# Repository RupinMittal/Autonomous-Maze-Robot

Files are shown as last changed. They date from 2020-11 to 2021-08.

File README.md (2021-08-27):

# Autonomous Maze Robot

The top right corner is the end of the maze. See the Demo folder for full videos, and below for an overview
of the project. 

maze1
maze2


## Made with IEEE UCLA

### Description

This project is an autononmous maze navigating robot. It was built from scratch with 
the help of IEEE at UCLA (and my leads Bradley Schulz and Tyler Price).

To see the code, go to Code-SRC.
To run the code on your micromous, download the MicroMouse-STM32IDE.zip file, and open in the STM32 Cube IDE, 
so that you have the STM-configured files ready to go. Your robot will need to match the same port connections
in the schematics.

The test for the robots was a modified verison of the AAMC competition at UCLA where the top right corner is
considered the end of the maze.

### Software

The microcontroller used was the STM 32 Microcontoller, so the embedded programs were written in 
the C programming language. 

Includes:
- Motor Control (PID)
- IR Sensor based control
- Floodfill Algorithm
- Simulator (the base of the simulator was written by Tyler Price at IEEE)

The files included in this repository are only the code I wrote, and not the files automatically 
configured by the STM 32 Cube IDE. 

### Hardware 

The base PCB was built by Bradley Schulz and Tyler Price from IEEE UCLA. I have made 
my own schematic designs for the whole project (included in this repository). All schematics were 
made with EAGLE. I designed the IR sensor PCB from scratch using EAGLE software as well.

- Power Board Schematic
- H-Bridge Schematic
- IR Sensor PCB Board

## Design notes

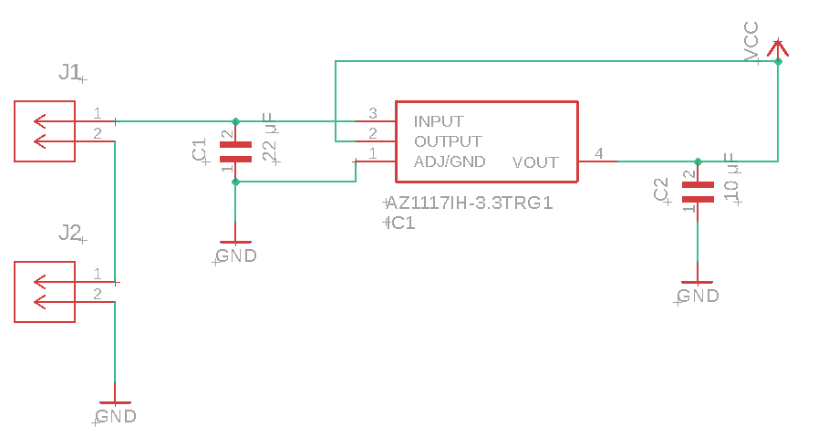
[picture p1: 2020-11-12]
Schematics-PCBs/Power Regulator Schematic.png

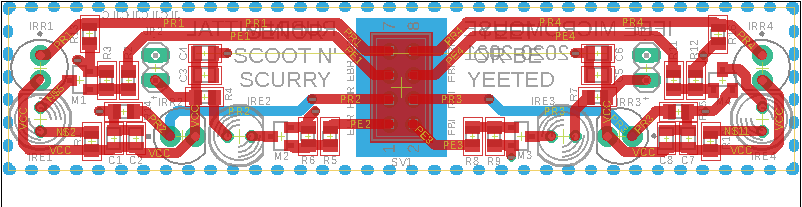
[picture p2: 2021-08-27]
Schematics-PCBs/IR PCB Image.png

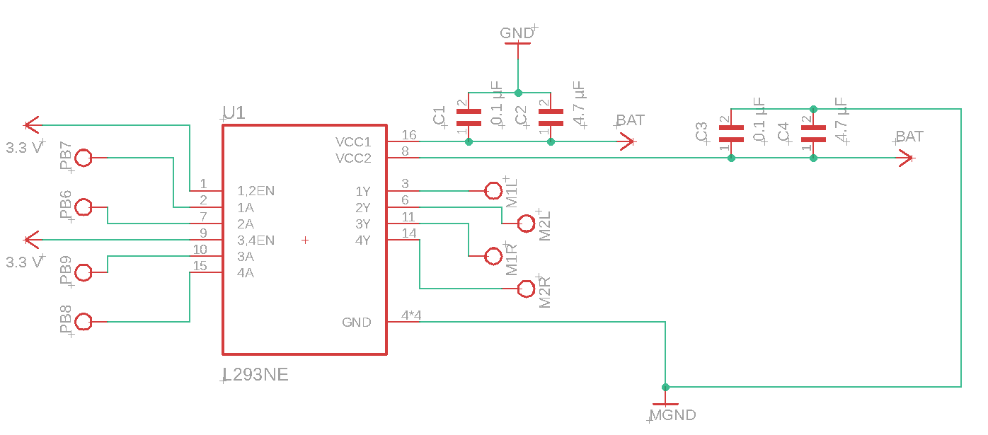
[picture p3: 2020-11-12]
Schematics-PCBs/H-Bridge Schematic.png

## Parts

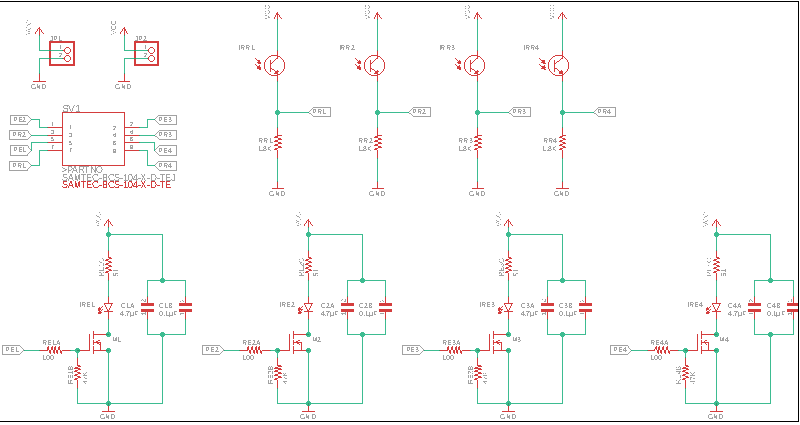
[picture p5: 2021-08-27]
Schematics-PCBs/IR PCB Components.png

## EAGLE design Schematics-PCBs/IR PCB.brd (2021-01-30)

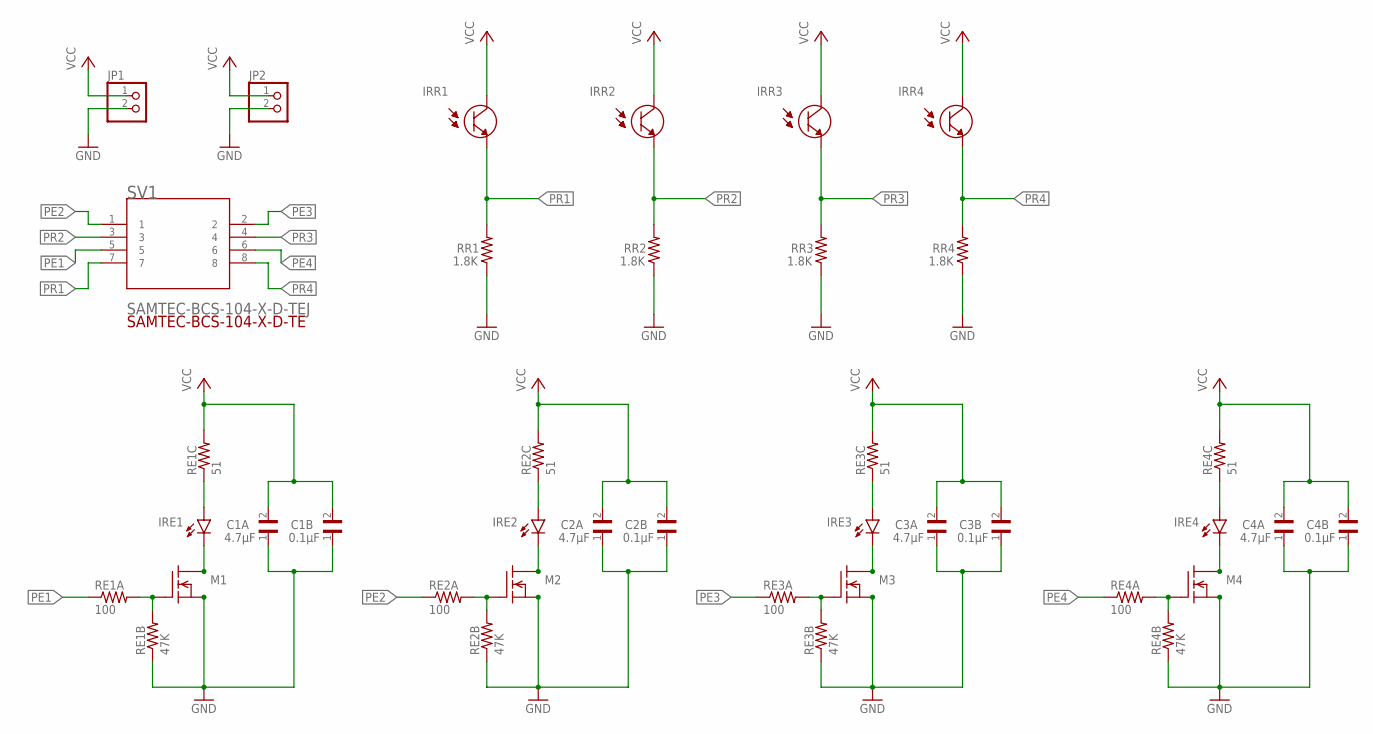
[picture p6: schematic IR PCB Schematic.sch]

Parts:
C1A, C2A, C3A, C4A: 4.7μF; CAPC2012X140N
C1B, C2B, C3B, C4B: 0.1μF; CAPC2012X140N
IRE1, IRE2, IRE3, IRE4: LED5MM
IRR1, IRR2, IRR3, IRR4: SFH_313_FA-3/4; XDCR_SFH_313_FA-3/4
JP1, JP2: PINHD-1X2; 1X02
M1, M2, M3, M4: 2N7002; SOT23
RE1A, RE2A, RE3A, RE4A: 100; R0805
RE1B, RE2B, RE3B, RE4B: 47K; R0805
RE1C, RE2C, RE3C, RE4C: 51; R0805
RR1, RR2, RR3, RR4: 1.8K; R0805
SV1: SAMTEC-BCS-104-X-D-TEJ; SAMTEC-BCS-104-X-D-TE

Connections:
GND: C1A.1, C1B.1, C2A.1, C2B.1, C3A.1, C3B.1, C4A.1, C4B.1, JP1.2, JP2.2, M1.2 (S), M2.2 (S), M3.2 (S), M4.2 (S), RE1B.1, RE2B.1, RE3B.1, RE4B.1, RR1.1, RR2.1, RR3.1, RR4.1
unnamed: M1.1 (G), RE1A.2, RE1B.2
unnamed: IRE1.A, RE1C.1
unnamed: M2.1 (G), RE2A.2, RE2B.2
unnamed: IRE2.A, RE2C.1
unnamed: IRE1.K (C), M1.3 (D)
unnamed: IRE2.K (C), M2.3 (D)
unnamed: M3.1 (G), RE3A.2, RE3B.2
unnamed: IRE3.A, RE3C.1
unnamed: IRE3.K (C), M3.3 (D)
unnamed: M4.1 (G), RE4A.2, RE4B.2
unnamed: IRE4.A, RE4C.1
unnamed: IRE4.K (C), M4.3 (D)
PE1: RE1A.1, SV1.5
PE2: RE2A.1, SV1.1
PE3: RE3A.1, SV1.2
PE4: RE4A.1, SV1.6
PR1: IRR1.1 (E), RR1.2, SV1.7
PR2: IRR2.1 (E), RR2.2, SV1.3
PR3: IRR3.1 (E), RR3.2, SV1.4
PR4: IRR4.1 (E), RR4.2, SV1.8
VCC: C1A.2, C1B.2, C2A.2, C2B.2, C3A.2, C3B.2, C4A.2, C4B.2, IRR1.2 (C), IRR2.2 (C), IRR3.2 (C), IRR4.2 (C), JP1.1, JP2.1, RE1C.2, RE2C.2, RE3C.2, RE4C.2

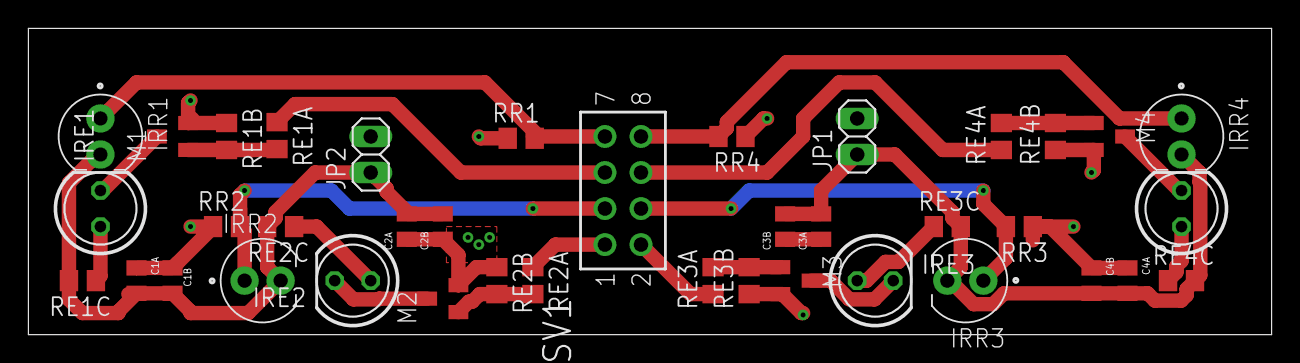
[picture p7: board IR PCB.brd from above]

Board: 2 copper layers, 87.6 x 21.6 mm, 39 parts (0 on the bottom side), 22 nets.

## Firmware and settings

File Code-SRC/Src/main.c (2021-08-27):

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
/* Includes ------------------------------------------------------------------*/
#include "main.h"

/* USER CODE BEGIN Includes */
#include "encoders.h"		//for getting the encoder counts
#include "motors.h"			//for motor control
#include "controller.h"		//for move and turn
/* USER CODE END Includes */

TIM_HandleTypeDef htim2;
TIM_HandleTypeDef htim4;
TIM_HandleTypeDef htim8;

/* USER CODE BEGIN PV */

int16_t left_encoder_counts = 0;	//variable for left encoder count
int16_t right_encoder_counts = 0;	//variable for right encoder count

float left_PWM = 0;
float right_PWM = 0;

/* USER CODE END PV */

void SystemClock_Config(void);
static void MX_GPIO_Init(void);
static void MX_TIM2_Init(void);
static void MX_TIM8_Init(void);
static void MX_TIM4_Init(void);
/**
  * @brief  The application entry point.
  * @retval int
  */
int main(void)
{
  /* MCU Configuration--------------------------------------------------------*/

  /* Reset of all peripherals, Initializes the Flash interface and the Systick. */
  HAL_Init();

  /* Configure the system clock */
  SystemClock_Config();

  /* Initialize all configured peripherals */
  MX_GPIO_Init();
  MX_TIM2_Init();
  MX_TIM8_Init();
  MX_TIM4_Init();
  /* USER CODE BEGIN 2 */

  HAL_TIM_Encoder_Start(&htim2, TIM_CHANNEL_ALL);	//for the encoders on tim2 (start them)
  HAL_TIM_Encoder_Start(&htim8, TIM_CHANNEL_ALL);	//for the encoders on tim4 (start them)

  HAL_TIM_PWM_Start(&htim4, TIM_CHANNEL_1);			//for the PWM on each of the 4 channels on tim4
  HAL_TIM_PWM_Start(&htim4, TIM_CHANNEL_2);
  HAL_TIM_PWM_Start(&htim4, TIM_CHANNEL_3);
  HAL_TIM_PWM_Start(&htim4, TIM_CHANNEL_4);


  /* USER CODE END 2 */

  /* Infinite loop */
  /* USER CODE BEGIN WHILE */	//something is not working right with doing multiple movements. Just doing one turn or one move is good, but multiple statements does not work. Could have something to do with resetting goals
 /*move(1);
 turn(1);
 move(1);
 turn(1);
 move(1);
 turn(1);
 move(1);
 turn(1);*/
  move(1);
  move(1);

  while (1)
  {
	left_encoder_counts = getLeftEncoderCounts();		//get the encoder counts on right motor
	right_encoder_counts = getRightEncoderCounts();		//get the encoder counts on left motor

	left_PWM = (float) TIM4->CCR2;
	right_PWM = (float) TIM4->CCR4;
  }

    /* USER CODE END WHILE */

}

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
/* USER CODE BEGIN 4 */
void HAL_GPIO_EXTI_Callback(uint16_t GPIO_Pin)
{
	if(GPIO_Pin == PushButton_Pin)	//if the push button was pressed
	{
		GPIO_PinState PinState = HAL_GPIO_ReadPin(PushButton_GPIO_Port, GPIO_Pin);	//get the state of the pin
		PinState = (PinState == GPIO_PIN_SET) ? GPIO_PIN_RESET : GPIO_PIN_SET;		//since button is pulled high (high voltage when not pressed and low voltage when not pressed), just invert it's result
		HAL_GPIO_WritePin(LED_GPIO_Port, LED_Pin, PinState);						//write out to the LED
	}
}
/* USER CODE END 4 */
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


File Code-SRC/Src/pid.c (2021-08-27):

/*
 * pid.c
 *
 *  Created on: Sep 27, 2020
 *      Author: Tyler Price
 */

#include "main.h"
#include "motors.h"
#include "encoders.h"
#include "pid.h"		//I added this in since it wasn't there before

//global variables (so they show up in Live Expressions debugging interface)

	const float kP_distance = 0.25;					//how aggresively we want to respond to distance errors
	const float kD_distance = 0.4;					//factor for responding to how close we are to reaching our target distance

	const float kP_angle = 0.25;						//how aggresively we want to respond to angle errors
	const float kD_angle = 0.4;					//factor for responding to how close we are to reaching our target angle

	int angleError = 0;							//errors in the angle (in encoder counts)
	int oldAngleError = 0;						//for calculating kD_angle

	float distanceError = 0;					//how many encoder counts we are from our target (in encoder counts)
	float oldDistanceError = 0;					//for calculating kD_distance

	float angleCorrection;						//correction values in pwm values
	float distanceCorrection;

	int16_t goal_distance = 0;					//goal values to be updated by setPIDGoal functions
	int16_t goal_angle = 0;

	int count_Error_Zero = 0; 					//keeps track of how many SysTick calls the error has been sufficiently close to zero for
	const int NUM_ZERO_ERROR_FOR_GOAL = 75; 	//number of calls with close to zero error required for goal to be met
	const double zero_error = 5; 				//max error that is considered sufficiently close to zero error
	int goal_met = 0; 							//is the goal met of not

	const float MAX_ANGLE_CORRECTION = 0.3;		//maximum correction values
	const float MAX_DISTANCE_CORRECTION = 0.5;

void resetPID()
{
	/*
	 * For assignment 3.1: This function does not need to do anything
	 * For assignment 3.2: This function should reset all the variables you define in this file to help with PID to their default
	 *  values. You should also reset your motors and encoder counts (if you tell your rat to turn 90 degrees, there will be a big
	 * difference in encoder counts after it turns. If you follow that by telling your rat to drive straight without first
	 * resetting the encoder counts, your rat is going to see a huge angle error and be very unhappy).
	 *
	 * You should additionally set your distance and error goal values (and your oldDistanceError and oldAngleError) to zero.
	 */

	resetEncoders();			//reset motors and encoders
	resetMotors();

	angleError = 0;				//reset errprs
	oldAngleError = 0;

	distanceError = 0;
	oldDistanceError = 0;

	angleCorrection = 0;		//reset corrections
	distanceCorrection = 0;

	goal_angle = 0;				//reset goals, otherwise it will move twice instead of just once, since PID will reset and it will try to reach goal again since updatePID() is still running
	goal_distance = 0;

	count_Error_Zero = 0;		//reset values for testing if PID is done
	goal_met = 0;

}

void updatePID()
{
	/*
	 * This function will do the heavy lifting PID logic. It should do the following: read the encoder counts to determine an error,
	 * use that error along with some PD constants you determine in order to determine how to set the motor speeds, and then actually
	 * set the motor speeds.
	 *
	 * For assignment 3.1: implement this function to get your rat to drive forwards indefinitely in a straight line. Refer to pseudocode
	 * example document on the google drive for some pointers
	 *
	 * TIPS (assignment 3.1): Create kPw and kDw variables, use a variable to store the previous error for use in computing your
	 * derivative term. You may get better performance by having your kDw term average the previous handful of error values instead of the
	 * immediately previous one, or using a stored error from 10-15 cycles ago (stored in an array?). This is because systick calls so frequently
	 * that the error change may be very small and hard to operate on.
	 *
	 * For assignment 3.2: implement this function so it calculates distanceError as the difference between your goal distance and the average of
	 * your left and right encoder counts. Calculate angleError as the difference between your goal angle and the difference between your left and
	 * right encoder counts. Refer to pseudocode example document on the google drive for some pointers.
	 */

	angleError = goal_angle - (getLeftEncoderCounts() - getRightEncoderCounts());					//the error is the difference between the goal angle the delta of the encoder counts
	angleCorrection = (kP_angle * angleError) + (kD_angle * (angleError - oldAngleError));			//the correction in pwm values
	oldAngleError = angleError;																		//set old error to current error (for derivative component)

	angleCorrection = limit_angle_correction(angleCorrection);

	distanceError = goal_distance + ((getLeftEncoderCounts() + getRightEncoderCounts()) / 2);					//the error is goal distance - average of encoder counts
	distanceCorrection = (kP_distance * distanceError) + (kD_distance * (distanceError - oldDistanceError));	//the correction in pwm values
	oldDistanceError = distanceError; 																			//set old error to the current error

	distanceCorrection = limit_distance_correction(distanceCorrection);

	setMotorLPWM(distanceCorrection + angleCorrection);									//set motors to corrected values
	setMotorRPWM(distanceCorrection - angleCorrection);

	if ((absolute_value(angleError) < zero_error) && (absolute_value(distanceError) < zero_error))			//if error is sufficiently close to zero
		count_Error_Zero++;																					//increment number of times the error has been consecutively close to zero
	else
	{
		count_Error_Zero = 0;
		goal_met = 0;
	}
	if (count_Error_Zero > NUM_ZERO_ERROR_FOR_GOAL)															//if error has been sufficiently close to zero enough times
		goal_met = 1;																						//the goal has been met
}

void setPIDGoalD(int16_t distance)
{
	/*
	 * For assignment 3.1: this function does not need to do anything.
	 * For assignment 3.2: this function should set a variable that stores the goal distance.
	 */

	goal_distance = distance;
}

void setPIDGoalA(int16_t angle)
{
	/*
	 * For assignment 3.1: this function does not need to do anything
	 * For assignment 3.2: This function should set a variable that stores the goal angle.
	 */

	goal_angle = angle;
}

int8_t PIDdone(void)
{
	/*
	 * For assignment 3.1: this function does not need to do anything (your rat should just drive straight indefinitely)
	 * For assignment 3.2:This function should return true if the rat has achieved the set goal. One way to do this by having updatePID() set some variable when
	 * the error is zero (realistically, have it set the variable when the error is close to zero, not just exactly zero). You will have better results if you make
	 * PIDdone() return true only if the error has been sufficiently close to zero for a certain number, say, 50, of SysTick calls in a row.
	 */

	return goal_met;
}
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

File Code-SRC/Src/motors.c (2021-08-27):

/*
 * motors.c
 *
 *  Created on: Sep 10, 2020
 *      Author: Tyler Price
 */

#include "motors.h"

/*
 * This function should return PWM_MAX if pwm > PWM_MAX, -PWM_MAX if pwm < -PWM_MAX, and pwm otherwise.
 */
float limitPWM(float pwm)
{
	if(pwm > PWM_MAX)
			return PWM_MAX;
	else
	{
		if(pwm < -PWM_MAX)
			return -PWM_MAX;
		else
			return pwm;
	}
}

/*
 * This function controls the left motor speed and direction. We do this by setting the timer pulse value for the appropriate channel.
 * All our H-bridge inputs use timer 4. TIM4->CCRX = (uint32_t) (limitPWM(pwm) * MAX_TIMER_COUNTS) sets the pulse value for channel x.
 * For the left motor, setting channel 2 makes the wheel spin forward and setting channel 1 makes the wheel spin backwards.
 *
 * The parameter pwm is a value between 0 and 1, representing the percentage of maximum speed to turn the motor. e.g. 0.5 is half speed.
 *
 * IMPORTANT: NEVER SET BOTH THE FORWARD AND BACKWARD CHANNELS TO NON-ZERO VALUES AT THE SAME TIME. As mentioned in lecture, this can
 * destroy your h-bridge. When setting a channel, always set the other channel to zero first.
 *
 * Implement this function to make the left wheel spin forwards when pwm is >= 0, and spin backwards when pwm < 0.
 */
void setMotorLPWM(float pwm)
{
	if(pwm >= 0)	//if pwm >= 0, make wheel spin forwards (channel 2 is forwards)
	{
		TIM4->CCR1 = (uint32_t) 0;										//first set backwards to 0
		TIM4->CCR2 = (uint32_t) (limitPWM(pwm) * MAX_TIMER_COUNTS);		//then set forwards to speed
	}
	else			//if pwm < 0, make wheel spin backwards (channel 1 is backwards)
	{
		TIM4->CCR2 = (uint32_t) 0;										//first set forwards to 0
		TIM4->CCR1 = (uint32_t) (limitPWM(-pwm) * MAX_TIMER_COUNTS);	//then set backwards to speed, to -pwm since speed can only be positive
	}
}

/*
 * This function controls the right motor speed and direction. We do this by setting the timer pulse value for the appropriate channel.
 * All our H-bridge inputs use timer 4. TIM4->CCRX = (uint32_t) (limitPWM(pwm) * MAX_TIMER_COUNTS) sets the pulse value for channel x.
 * For the right motor, setting channel 4 makes the wheel spin forward and setting channel 3 makes the wheel spin backwards.
 *
 * The parameter pwm is a value between 0 and 1, representing the percentage of maximum speed to turn the motor. e.g. 0.5 is half speed.
 *
 * IMPORTANT: NEVER SET BOTH THE FORWARD AND BACKWARD CHANNELS TO NON-ZERO VALUES AT THE SAME TIME. As mentioned in lecture, this can
 * destroy your h-bridge. When setting a channel, always set the other channel to zero first.
 *
 * Implement this function to make the right wheel spin forwards when pwm is >= 0, and spin backwards when pwm < 0.
 */
void setMotorRPWM(float pwm)
{
	if(pwm >= 0)	//if pwm >= 0, make wheel spin forwards (channel 4 is forwards)
	{
		TIM4->CCR3 = (uint32_t) 0;										//first set backwards to 0
		TIM4->CCR4 = (uint32_t) (limitPWM(pwm) * MAX_TIMER_COUNTS);		//then set forwards to speed
	}
	else			//if pwm < 0, make wheel spin backwards (channel 3 is backwards)
	{
		TIM4->CCR4 = (uint32_t) 0;										//first set forwards to 0
		TIM4->CCR3 = (uint32_t) (limitPWM(-pwm) * MAX_TIMER_COUNTS);	//then set backwards to speed, to -pwm since speed can only be positive
	}
}

/*
 * Using the two previous setMotorPWM functions, implement resetMotors to set the PWM for both wheels to zero, effectively stopping them.
 */
void resetMotors()
{
	setMotorLPWM(0);	//set left motor pwm to 0
	setMotorRPWM(0);	//set right motor pwm to 0
}

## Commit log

2020-11-12 LED Switch code (works)
2020-11-12 Encoder code to get encoder counts (works)
2020-11-12 Basic motor movement code
2020-11-12 Power Regulator and H-Bridge Schematics
2020-12-22 PID control for straight line
2021-01-13 Fixed bugs in code to turn, added code to move forward/back (works)
    [controller.c, main.c, pid.c]
2021-01-30 Draft of IR PCB
    [IR PCB .brd, IR PCB Schematic.sch]
2021-08-27 Additional Schematics/PCBs
    [H-Bridge.sch, IR PCB Schematic.sch, IR PCB.brd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]
2021-08-27 Renamed Files:
    [H-Bridge.sch, IR PCB Schematic.sch, IR PCB.brd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]

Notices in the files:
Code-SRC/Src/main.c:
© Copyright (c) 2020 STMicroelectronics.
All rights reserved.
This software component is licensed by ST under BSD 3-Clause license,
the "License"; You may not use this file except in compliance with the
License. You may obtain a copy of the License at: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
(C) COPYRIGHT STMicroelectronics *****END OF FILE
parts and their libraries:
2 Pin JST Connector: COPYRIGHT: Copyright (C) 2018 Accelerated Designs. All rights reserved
